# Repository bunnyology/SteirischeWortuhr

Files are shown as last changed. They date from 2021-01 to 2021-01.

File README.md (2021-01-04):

# SteirischeWortuhr
Wortuhr im steirischen Dialekt (Arduino/3D Druck)

Diese Wortuhr zeigt die aktuelle Uhrzeit auf Steirisch an. Dabei sind nicht nur die Zahlenworte in Mundart gehalten, sondern auch die eigentümliche- und für Nicht-Steirer wohl auch verwirrende Angabe der Uhrzeit ist dem lokalen Sprachgebrauch nachempfunden (14 Uhr 15 wird z.B. als "viertel Drei (!)" angegeben.

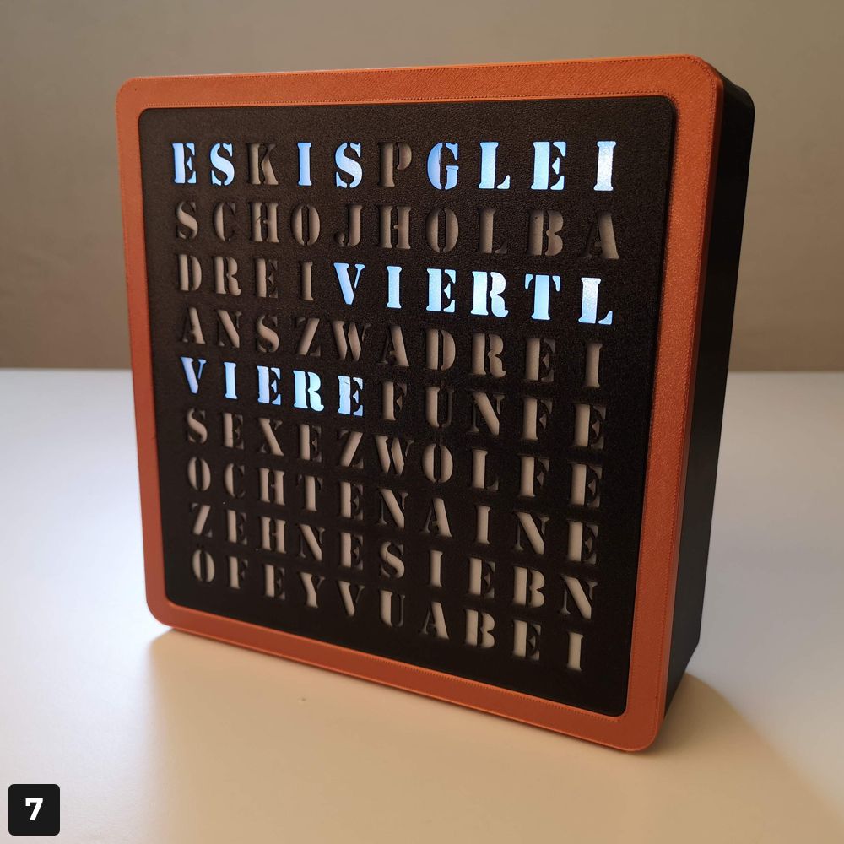
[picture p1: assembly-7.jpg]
Wortuhr


# Elektronik
Gesteuert wird die Uhr mit einem Arduino Nano und ein DCF-77 Funkuhrempfänger stellt die Zeit automatisch sekundengenau ein.

Sollte man nicht im 1500km Umkreis von Frankfurt wohnen, kann diese Antenne auch eingespart, und die Uhrzeit mit der Taste eingestellt werden.

Ich habe versucht, die Elektronik so simpel wie nur Möglich zu halten und auch auf LED Treiber verzichtet. Der Arduino treibt die eingesetzten 5mm LEDs ohne weitere Elektronik. Dafür habe ich Ultrabright LEDs eingesetzt (ca. 14000 mcd bei 20mA) und treibe diese mit 4mA um unter den Limits des Microcontrollers u bleiben. Da jedoch diese Ultrabright LEDs meistens einen sehr engen Abstrahlwinkel haben (was zu einer unregelmäßigen Ausleuchtung führen würde), habe ich die Köpfe der LEDs flach abgeschliffen.

Um die "Produktion" zu vereinfachen, habe ich eine eigene Platine fertigen lassen. Die KiCAD Schematics und PCB Daten sind hier herunterladbar, ebenso die Gerber Daten für die Platinenproduktion. Will man aber nur eine einzige Uhr herstellen, kann die Elektronik auch ganz einfach nur verkabelt werden. Der Verdratungsplan ist recht simpel:

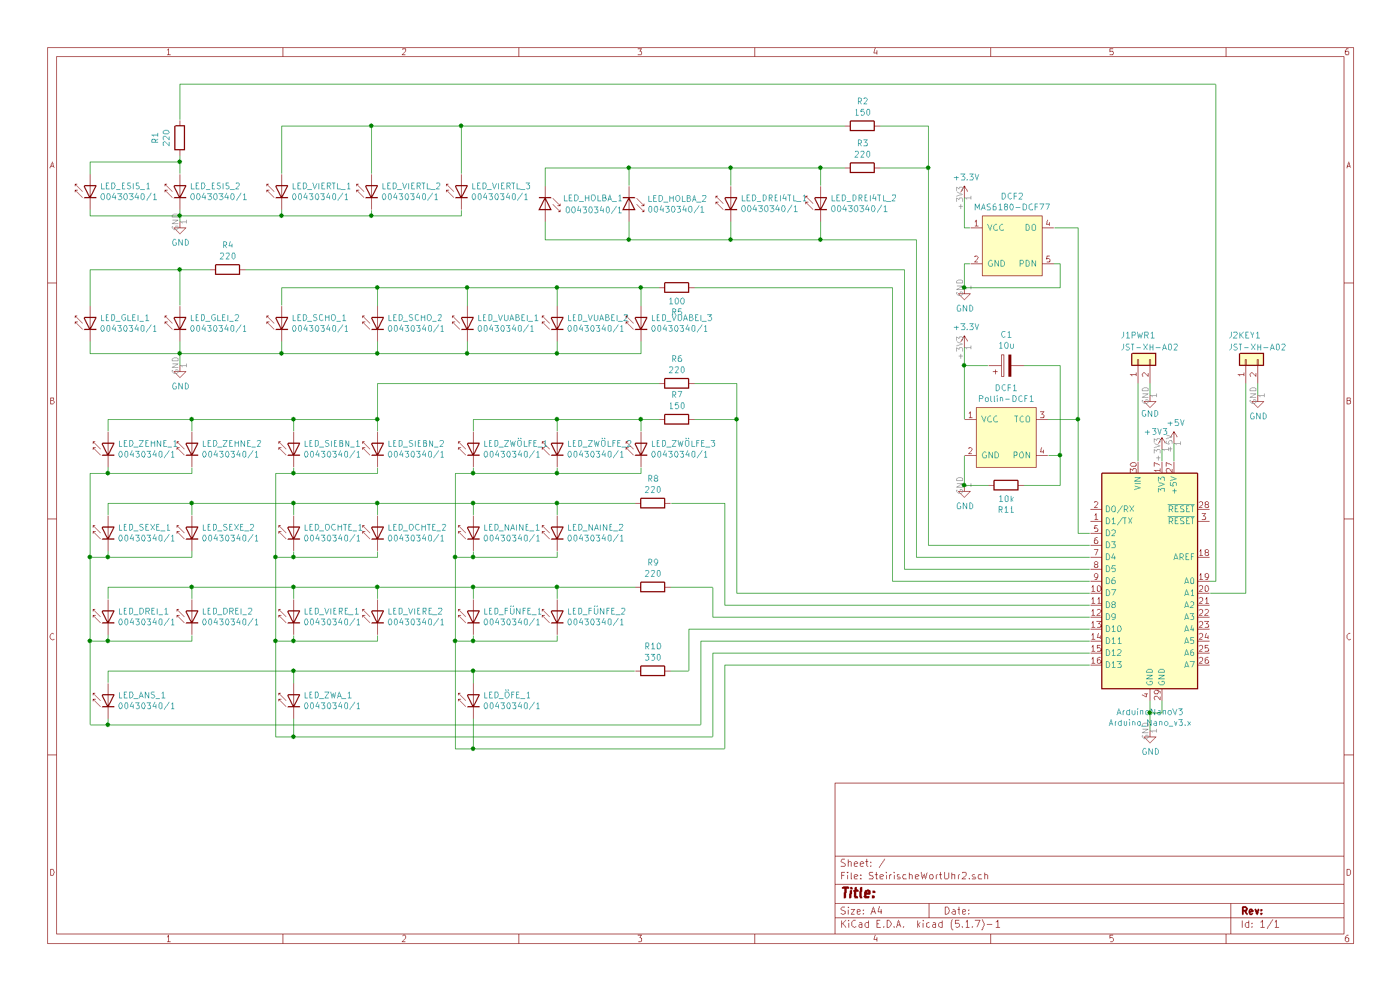
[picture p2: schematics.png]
Verdratungsplan


# Bedienung der Wortuhr
Die Uhr wird über ein 12V Netzteil mit Strom versorgt und startet beim Einstecken des Netzteilsteckers automatisch. Wird während des Einschaltens der Taster gedrückt, startet der Selbstcheck (die Uhr läuft einen 12 Stunden Zyklus schnell durch).

Solange kein Zeitpacket empfangen wird blinkt "GLEI" im Sekundentakt. Wird ein Synchronisationssignal erkannt (jede volle Minute), erhöht sich die Blinkgeschindigkeit (500ms). Sobald die Zeitinformation empfangen wird (ab Sekunde 20), verdoppelt sich die Blinkgeschwindigkeit noch einmal, bis die gesamte Uhrzeit eingelesen wurde. Dann wird die empfangene Uhrzeit angezeigt.

Hinweis: Das DCF-77 Signal ist recht schwach, und daher die Ausrichtung der Antenne wichtig. Die Uhr solle für einen guten Empfang nach Frankfurt ausgerichtet sein (Anzeige in oder gegen Blickrichtung Frankfurt).

Ist ein Empfang nicht möglich, kann die Uhrzeit auch über den Taster eingestellt werden. Dazu muss der Taster 3 Sekunden gedrückt gehalten werden. "ES IS" fängt dann zu blinken an und mit weiteren kurzen Tastendrucks kann die Uhrzeit in 5 Minuten Schritten eingestellt werden. Erneutes 3 Sekunden Drücken speichert die Uhrzeit und "ES IS" leuchtet wieder konstant.
Sobald ein Zeitpacket empfangen wird, synchronisiert sich die Uhrzeit wieder automatisch.

Die Helligkeit der Anzeige kann in vier Stufen durch kurzes Drücken des Tasters eingestellt werden.

# 3D Druck

Die 3D Modelle und Druckdateien können hier heruntergeladen werden:

https://www.prusaprinters.org/prints/44454-steirische-wort-uhr-styrian-dialect-word-clock

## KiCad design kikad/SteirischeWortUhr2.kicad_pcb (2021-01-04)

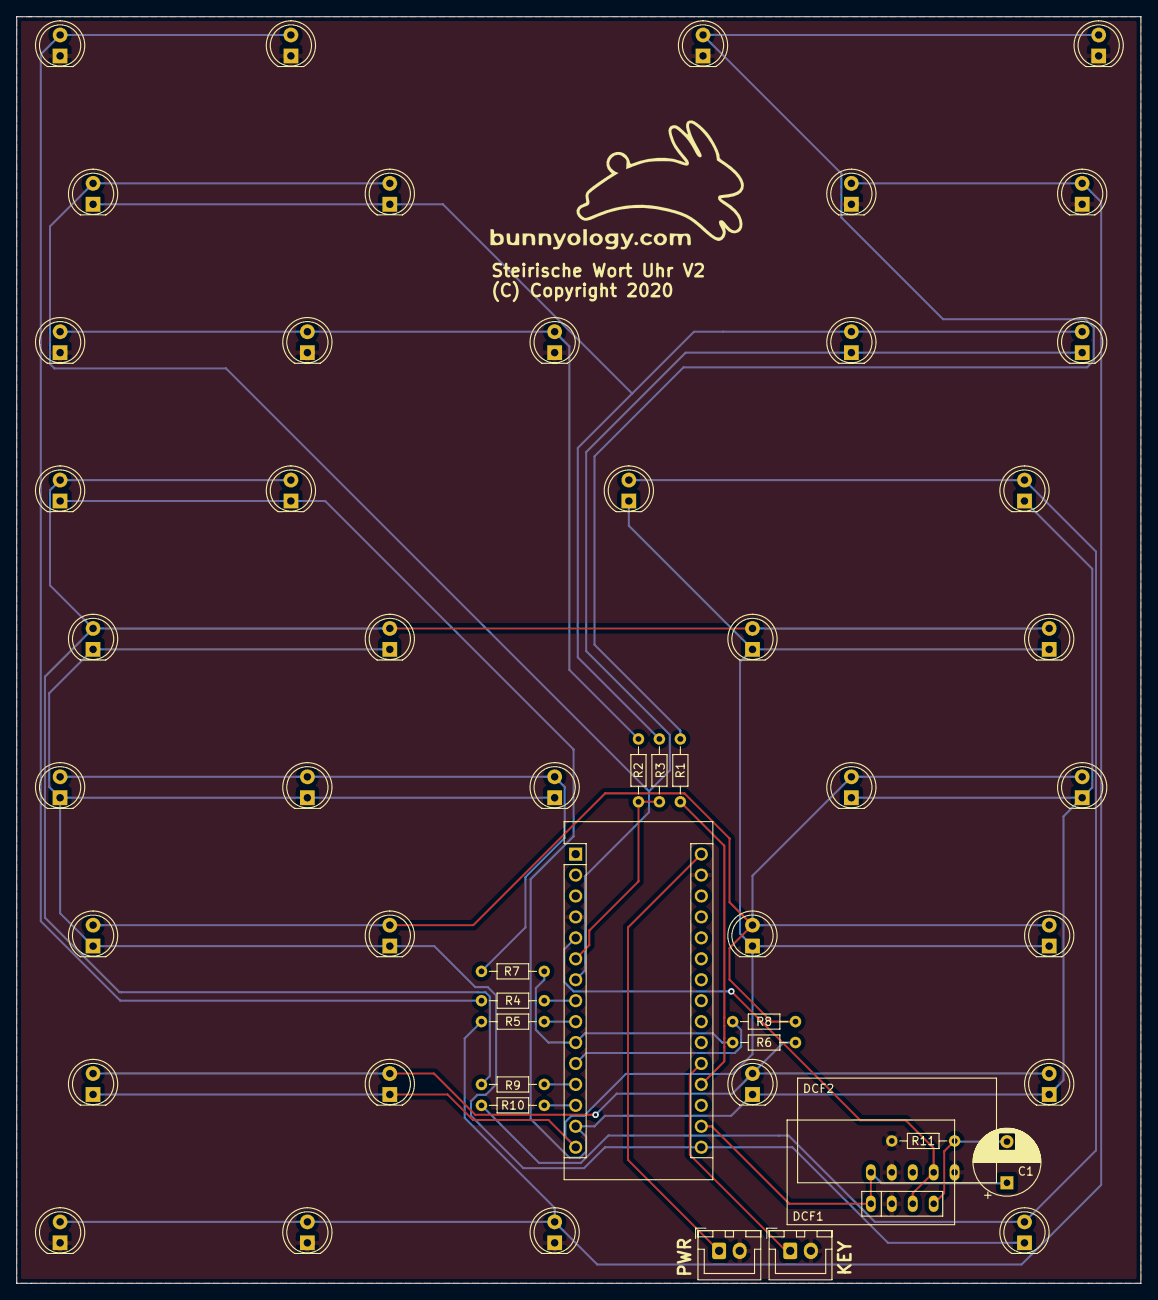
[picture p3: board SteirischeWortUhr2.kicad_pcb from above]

Board: 2 copper layers, 136.4 x 153.7 mm, 55 parts (0 on the bottom side), 28 nets.

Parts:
ArduinoNanoV3: Arduino_Nano_v3.x; Arduino_Nano
C1: 10u; CP_Radial_D8.0mm_P5.00mm
DCF1: Pollin-DCF1; Pollin-DFC77
DCF2: MAS6180-DCF77; MAS6180B1-DFC77
J1PWR1, J2KEY1: JST-XH-A02; JST_XH_B2B-XH-A_1x02_P2.50mm_Vertical
LED_ANS_1: 00430340/1; LED_D5.0mm_IRGrey
LED_DREI4TL_1, LED_DREI4TL_2: 00430340/1; LED_D5.0mm_IRGrey
LED_DREI_1, LED_DREI_2: 00430340/1; LED_D5.0mm_IRGrey
LED_ESIS_1, LED_ESIS_2: 00430340/1; LED_D5.0mm_IRGrey
LED_FÜNFE_1, LED_FÜNFE_2: 00430340/1; LED_D5.0mm_IRGrey
LED_GLEI_1, LED_GLEI_2: 00430340/1; LED_D5.0mm_IRGrey
LED_HOLBA_1, LED_HOLBA_2: 00430340/1; LED_D5.0mm_IRGrey
LED_NAINE_1, LED_NAINE_2: 00430340/1; LED_D5.0mm_IRGrey
LED_OCHTE_1, LED_OCHTE_2: 00430340/1; LED_D5.0mm_IRGrey
LED_SCHO_1, LED_SCHO_2: 00430340/1; LED_D5.0mm_IRGrey
LED_SEXE_1, LED_SEXE_2: 00430340/1; LED_D5.0mm_IRGrey
LED_SIEBN_1, LED_SIEBN_2: 00430340/1; LED_D5.0mm_IRGrey
LED_VIERE_1, LED_VIERE_2: 00430340/1; LED_D5.0mm_IRGrey
LED_VIERTL_1, LED_VIERTL_2, LED_VIERTL_3: 00430340/1; LED_D5.0mm_IRGrey
LED_VUABEI_1, LED_VUABEI_2, LED_VUABEI_3: 00430340/1; LED_D5.0mm_IRGrey
LED_ZEHNE_1, LED_ZEHNE_2: 00430340/1; LED_D5.0mm_IRGrey
LED_ZWA_1: 00430340/1; LED_D5.0mm_IRGrey
LED_ZWÖLFE_1, LED_ZWÖLFE_2, LED_ZWÖLFE_3: 00430340/1; LED_D5.0mm_IRGrey
LED_ÖFE_1: 00430340/1; LED_D5.0mm_IRGrey
R1, R3, R4, R6, R8, R9: 220; R_Axial_DIN0204_L3.6mm_D1.6mm_P7.62mm_Horizontal
R2, R7: 150; R_Axial_DIN0204_L3.6mm_D1.6mm_P7.62mm_Horizontal
R5: 100; R_Axial_DIN0204_L3.6mm_D1.6mm_P7.62mm_Horizontal
R10: 330; R_Axial_DIN0204_L3.6mm_D1.6mm_P7.62mm_Horizontal
R11: 10k; R_Axial_DIN0204_L3.6mm_D1.6mm_P7.62mm_Horizontal

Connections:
+3V3: ArduinoNanoV3.17, C1.1, DCF1.1, DCF2.1
GND: ArduinoNanoV3.4, ArduinoNanoV3.29, DCF1.2, DCF2.2, DCF2.5, J1PWR1.2, J2KEY1.2, LED_ESIS_1.1, LED_ESIS_2.1, LED_GLEI_1.1, LED_GLEI_2.1, LED_SCHO_1.1, LED_SCHO_2.1, LED_VIERTL_1.1, LED_VIERTL_2.1, LED_VIERTL_3.1, LED_VUABEI_1.1, LED_VUABEI_2.1, LED_VUABEI_3.1, R11.1
unnamed: ArduinoNanoV3.5, DCF1.3, DCF2.4
unnamed: ArduinoNanoV3.6, R2.1, R3.1
unnamed: ArduinoNanoV3.7, LED_DREI4TL_1.1, LED_DREI4TL_2.1, LED_HOLBA_1.2, LED_HOLBA_2.2
unnamed: ArduinoNanoV3.8, R4.1
unnamed: ArduinoNanoV3.9, R5.2
unnamed: ArduinoNanoV3.10, R6.1, R7.1
unnamed: ArduinoNanoV3.11, R8.1
unnamed: ArduinoNanoV3.12, R9.1
unnamed: ArduinoNanoV3.13, R10.1
unnamed: ArduinoNanoV3.14, LED_ANS_1.1, LED_DREI_1.1, LED_DREI_2.1, LED_SEXE_1.1, LED_SEXE_2.1, LED_ZEHNE_1.1, LED_ZEHNE_2.1
unnamed: ArduinoNanoV3.15, LED_OCHTE_1.1, LED_OCHTE_2.1, LED_SIEBN_1.1, LED_SIEBN_2.1, LED_VIERE_1.1, LED_VIERE_2.1, LED_ZWA_1.1
unnamed: ArduinoNanoV3.16, LED_FÜNFE_1.1, LED_FÜNFE_2.1, LED_NAINE_1.1, LED_NAINE_2.1, LED_ZWÖLFE_1.1, LED_ZWÖLFE_2.1, LED_ZWÖLFE_3.1, LED_ÖFE_1.1
unnamed: ArduinoNanoV3.19, R1.1
unnamed: ArduinoNanoV3.20, J2KEY1.1
unnamed: ArduinoNanoV3.30, J1PWR1.1
unnamed: C1.2, DCF1.4, R11.2
unnamed: LED_ANS_1.2, LED_ZWA_1.2, LED_ÖFE_1.2, R10.2
unnamed: LED_DREI4TL_1.2, LED_DREI4TL_2.2, LED_HOLBA_1.1, LED_HOLBA_2.1, R3.2
unnamed: LED_DREI_1.2, LED_DREI_2.2, LED_FÜNFE_1.2, LED_FÜNFE_2.2, LED_VIERE_1.2, LED_VIERE_2.2, R9.2
unnamed: LED_ESIS_1.2, LED_ESIS_2.2, R1.2
unnamed: LED_GLEI_1.2, LED_GLEI_2.2, R4.2
unnamed: LED_NAINE_1.2, LED_NAINE_2.2, LED_OCHTE_1.2, LED_OCHTE_2.2, LED_SEXE_1.2, LED_SEXE_2.2, R8.2
unnamed: LED_SCHO_1.2, LED_SCHO_2.2, LED_VUABEI_1.2, LED_VUABEI_2.2, LED_VUABEI_3.2, R5.1
unnamed: LED_SIEBN_1.2, LED_SIEBN_2.2, LED_ZEHNE_1.2, LED_ZEHNE_2.2, R6.2
unnamed: LED_VIERTL_1.2, LED_VIERTL_2.2, LED_VIERTL_3.2, R2.2
unnamed: LED_ZWÖLFE_1.2, LED_ZWÖLFE_2.2, LED_ZWÖLFE_3.2, R7.2

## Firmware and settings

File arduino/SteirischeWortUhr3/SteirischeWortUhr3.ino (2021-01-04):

/* ----------------------------------------------------------------------
 * Steirische Wort Uhr
 * ----------------------------------------------------------------------
 * Version: 3 / 01.11.2020
 * Target: Arduino Nano, ATmega328 
 * Copyright (C) 2020 by bunnyology
 * Author: Thomas Hasiba
 * 
 */

// a high/low cycle:
volatile unsigned long t0HI, t0LO;
volatile int tHI, tLO;

const int tolerance = 50;     // time tolerance of DCF signal in ms

volatile int rcvBIT;          // next index of bit to read in current packet (or -1 if stream is not synchronized)
volatile unsigned int tc;     // bits 20-35 of current packet

// The following variables are used to hand over a recevied time from the interrupt service
// routine to the main loop.
volatile unsigned int timecode;           // "tc" is copied into here, when 35th bit is read
volatile unsigned long timecode_millis;   // millis when "timecode" became valid (second 36 of minute)

// the actual time is stored here (once the time is set)
int tt_hour, tt_min, tt_sec, tt_ms;       // "readable" time of clock
unsigned long tt_millis;                  // time of last clock update

bool modeSync;                // when the time is set, this becomes "true"
bool modeSetup;               // "true", when the clock is in setup mode

const unsigned long LOOP_DELAY = 5;

int keyDown;                  // counts the time, the key is pressed

const int KEYDOWN_ENTER = 3000 / LOOP_DELAY;
const int KEYDOWN_RESET = 6000 / LOOP_DELAY;
const int KEYDOWN_CLICK = 1000 / LOOP_DELAY;

// this pwm pattern is controlling the light brightness by swithcing on/off the lights according to the pattern
unsigned int pwmMode = 0;
unsigned int pwmIdx = 0;
bool pwmPattern[6];

const bool PWM_PATTERN_0[] = { true, true, true, true, true, true };
const bool PWM_PATTERN_1[] = { true, true, false, true, true, false };
const bool PWM_PATTERN_2[] = { true, false, true, false, true, false };
const bool PWM_PATTERN_3[] = { true, false, false, true, false, false };


const int PIN_DCF77 = 2;      // pin 2 is connected to DCF77 output

// The array "pattern" contains the pattern for PORTD and PORTB output for cobinded
// minute and hour output.
// |                     PORTB                     |                    PORTD                      |
// +-----+-----+-----+-----+-----+-----+-----+-----|-----+-----+-----+-----+-----+-----+-----+-----+
// | 15  | 14  | 13  | 12  | 11  | 10  |  9  |  8  |  7  |  6  |  5  |  4  |  3  |  2  |  1  |  0  |
// |  ~  |  ~  |  -  |  -  |  -  |  +  |  +  |  +  |  +  | OVR | SOON| QUTR| HALF|  ~  |  ~  |  ~  |
// |     |     |5,9, |2,4, |1,3, |1,2, |3,4, |6,8, |7,10,|     |     |     |     |     |     |     |
// |     |     |11,12|7,8  |6,10 |  11 |  5, |  9, |  12 |     |     |     |     |     |     |     |
// +-----+-----+-----+-----+-----+-----+-----+-----|-----+-----+-----+-----+-----+-----+-----+-----+
// D0..7 in PORTD, D8..13 in PORTB

const unsigned int pattern[] =
  {
    (B00011000*256)+B10000000,      // 0h/12h ~ ES IS ...
    (B00110100*256)+B01000000,      // 1h/13h ~ ES IS "SCHO ... VUABEI"
    (B00101100*256)+B00111001,      // 2h/14h ~ ES IS "GLEI VIERTL ...(+1)"
    (B00110010*256)+B00011001,      // 3h/15h ~ ES IS "VIERTL ...(+1)"
    (B00101010*256)+B01011001,      // 4h/16h ~ ES IS "SCHO VIERTL ...(+1) VUABEI"
    (B00011010*256)+B00110001,      // 5h/17h ~ ES IS "GLEI HOLBA ...(+1)"
    (B00110001*256)+B00010001,      // 6h/18h ~ ES IS "HOLBA ...(+1)"
    (B00101000*256)+B11010001,      // 7h/19h ~ ES IS "SCHO HOLBA ...(+1) VUABEI"
    (B00101001*256)+B00101001,      // 8h/20h ~ ES IS "GLEI DREIVIERTL ...(+1)"
    (B00011001*256)+B00001001,      // 9h/21h ~ ES IS "DREIVIERTL ...(+1)"
    (B00110000*256)+B11001001,      // 10h/22h ~ ES IS "SCHO DREIVIERTL ...(+1) VUABEI"
    (B00011100*256)+B00100001       // 11h/23h ~ ES IS "GLEI ...(+1)"
  };

const unsigned int MASK_MINUTE =  (B00000000*256)+B01111000;
const unsigned int MASK_HOUR =    (B00111111*256)+B10000000;
const unsigned int MASK_INCDAY =  (B00000000*256)+B00000001;

// some special display commands...
const unsigned int CMD_OFF =      (B00111000*256)+B00000000;
const unsigned int CMD_WAIT =     (B00111000*256)+B00100000;    // "WAIT" display (blinks, when not sync'd)


void setup() {

  // setup all LED outputs
  pinMode( 3, OUTPUT );
  pinMode( 4, OUTPUT );
  pinMode( 5, OUTPUT );
  pinMode( 6, OUTPUT );
  pinMode( 7, OUTPUT );
  pinMode( 8, OUTPUT );
  pinMode( 9, OUTPUT );
  pinMode( 10, OUTPUT );
  pinMode( 11, OUTPUT );
  pinMode( 12, OUTPUT );
  pinMode( 13, OUTPUT );

  pinMode( A0, OUTPUT );
 
  // reset ALL OFF
  digitalWrite( A0, HIGH );
  setLightbox( CMD_OFF );

  // set input pin
  pinMode( A1, INPUT_PULLUP );

  // make visual check of Lightbox
  if( digitalRead( A1 ) == LOW ) {
    // key pressed during start-up -> run self check
    selfcheck();
  }

  // setup the DCF77 input
  t0HI = t0LO = 0;
  tHI = tLO = 0;
  rcvBIT = -1;
  timecode = 0;
  
  pinMode( PIN_DCF77, INPUT );    // the Pollin DCF77 does not work with INPUT_PULLUP
  attachInterrupt( digitalPinToInterrupt( PIN_DCF77 ), dcf77_isr, CHANGE );

  setPWMMode( 0 );
  modeSync = false;
  modeSetup = false;
}

void loop() {

  if( keyDown < 0 ) keyDown = 0;
  if( digitalRead( A1 ) == LOW ) {
    keyDown++;
  } else if( keyDown > 0 ) {
    keyDown = -keyDown;
  }

  if( modeSetup ) {

    if( keyDown == KEYDOWN_ENTER ) {
      // end set-up mode
      modeSetup = false;
      keyDown = KEYDOWN_CLICK; // set to KEYDOWN_CLICK to avoid triggering another click event
      modeSync = true;
      digitalWrite( A0, HIGH );
      tt_millis = millis();
      delay( LOOP_DELAY );
      return;
      
    } else if( keyDown > KEYDOWN_RESET ) {
      // long press -> reset
      keyDown = 0;
      modeSetup = false;
      modeSync = false;
      delay( LOOP_DELAY );
      return;
    }

    if(( keyDown < 0 ) && ( keyDown > -KEYDOWN_CLICK )) {
      incFiveMinutes();
    }

    // let "ES IS" blink
    if(( millis() % 500 ) < 250 ) digitalWrite( A0, HIGH ); else digitalWrite( A0, LOW );
    updateLightbox();

    delay( LOOP_DELAY );
    return;

  } else {
    // not in set-up mode yet
    if( keyDown > KEYDOWN_ENTER ) {
      // engage set-up mode
      tt_sec = 0;
      tt_min = ( tt_min / 5 ) * 5;
      modeSetup = true;
      delay( LOOP_DELAY );
      return;
    } else if(( keyDown < 0 ) && ( keyDown > -KEYDOWN_CLICK )) {
      // key clicked -> change brightness
      setPWMMode( ++pwmMode );
    }
  }

  
  
  if( timecode != 0 ) {
    // synchronization event

    // check validity of time packet
    if(( bitRead(timecode,0) == 0 )
      || (( bitRead(timecode,1)
           +bitRead(timecode,2)
           +bitRead(timecode,3)
           +bitRead(timecode,4)
           +bitRead(timecode,5)
           +bitRead(timecode,6)
           +bitRead(timecode,7)
           +bitRead(timecode,8)) % 2 == 1 )
      || (( bitRead(timecode,9)
           +bitRead(timecode,10)
           +bitRead(timecode,11)
           +bitRead(timecode,12)
           +bitRead(timecode,13)
           +bitRead(timecode,14)
           +bitRead(timecode,15)) % 2 == 1 )) {
      // time packet is invalid -> ignore
      timecode = 0;
      return;        
    }

    // set time
    int _min = bitRead(timecode,1)
        + 2*bitRead(timecode,2)
        + 4*bitRead(timecode,3)
        + 8*bitRead(timecode,4)
        + 10*bitRead(timecode,5)
        + 20*bitRead(timecode,6)
        + 40*bitRead(timecode,7);
    int _hour = bitRead(timecode,9)
        + 2*bitRead(timecode,10)
        + 4*bitRead(timecode,11)
        + 8*bitRead(timecode,12)
        + 10*bitRead(timecode,13)
        + 20*bitRead(timecode,14);

    // sanity check the time
    if(( _min > 59 ) || ( _hour > 23 )) {
      // time os nonsense -> ignore and reset package
      timecode = 0;
      return;
    }

    // the time seems to be valid -> set time of clock, now
    tt_hour = _hour;
    tt_min = _min;
    tt_sec = 36;      // we have still not read the full packet, we are in second 36 of previous minute
    tt_ms = 0;
    tt_millis = timecode_millis;

    // the minute decoded has not yet started; hence, set time to the minute before...
    decMinute();

    timecode = 0;
    modeSync = true;
    
    // show time of clock now
    updateLightboxPWM();

  } else if( modeSync ) {
    // time is sync'd
    
    // update time
    unsigned long ts = millis();
    // check for overflow
    int delta_ms = 0;
    if( ts < tt_millis ) {
      // handle timer overflow...
      delta_ms = 4294967295ul - tt_millis + ts + 1;
    } else {
      delta_ms = ts - tt_millis;      
    }

    if( tt_ms + delta_ms < 1000 ) {
      // does not increase seconds...
      tt_ms += delta_ms;
      tt_millis = ts;
      
    } else {
      delta_ms -= 1000 - tt_ms;
      tt_ms = 0;
      incSecond();
      while( delta_ms >= 1000 ) {
        delta_ms -= 1000;
        incSecond();
      }
      tt_ms += delta_ms;
      tt_millis = ts;
    }
    
    // time has probably changed -> update display
    updateLightboxPWM();

  } else {
    // not sync'd yet
    digitalWrite( A0, LOW );
    
    if( rcvBIT < 0 ) {
      if(( millis() % 2000 ) < 1000 ) setLightbox( CMD_OFF ); else setLightbox( CMD_WAIT );
    } else if( rcvBIT >= 20 ) {
      if(( millis() % 500 ) < 250 ) setLightbox( CMD_OFF ); else setLightbox( CMD_WAIT );
    } else {
      if(( millis() % 1000 ) < 500 ) setLightbox( CMD_OFF ); else setLightbox( CMD_WAIT );
    }
  }
  
  delay( LOOP_DELAY );
}


/** 
 * DCF77 Interrupt Handler
 */
void dcf77_isr() {
  long ts = millis();
  int state = digitalRead( PIN_DCF77 );
  if( state == LOW ) {
    // HIGH->LOW change - capture AMP-modulation spike
    tHI = ts - t0HI;
    t0LO = ts;
    return;
  }
  // LOW->HIGH change - capture carrier
  tLO = ts - t0LO;
  t0HI = ts;

  if( rcvBIT < 0 ) {
    // not sync'd - check for sync'ing pause (1800 or 1900ms)
    if(( tLO > 1800-tolerance ) && ( tLO < 1900+tolerance )) {
      // stream synchronization
      rcvBIT = 0;
      tc = 0;
    }
    return;
  }

  // try to match timings and identify bit value
  if(( tLO > 800-tolerance ) && ( tLO < 800+tolerance )) {
    // received "1"
    if(( rcvBIT >= 20 ) && ( rcvBIT < 36 )) {
      // time information
      bitSet( tc, rcvBIT-20 );
    }
    rcvBIT++;
    
  } else if(( tLO > 900-tolerance ) && ( tLO < 900+tolerance )) {
    // received "0"
    rcvBIT++;
    
  } else {
    // error - reset stream sync
    rcvBIT = -1;
    return;
  }
  if( rcvBIT == 36 ) {
    // time information is ready -> notify
    timecode_millis = ts;
    timecode = tc;
    
  } else if( rcvBIT == 59 ) {
    // packet finished 
    rcvBIT = -1;
  }
}

/**
 * incSecond
 * Increases the time of clock by one second, handling all overruns
 */
void incSecond() {
  tt_sec++;
  
  // check for second overflow
  if( tt_sec == 60 ) {
    tt_sec = 0;
    tt_min++;

    // check for minute overflow
    if( tt_min == 60 ) {
      tt_hour++;
      tt_min = 0;

      // check for hour overflow
      if( tt_hour == 24 ) tt_hour = 0;
    }
  }
}

/**
 * decMinute
 * Decreases the time of clock by one minute, handling all overruns.
 */
void decMinute() {
  if( tt_min > 0 ) {
    // no underrun
    tt_min--;
    return;
  }
  // handle minute underrun
  tt_min = 59;
  if( tt_hour > 0 ) {
    // no hour underron
    tt_hour--;
    return;
  }
  tt_hour = 23;
  return;
}

void incMinute() {
  tt_min++;

  // check for minute overflow
  if( tt_min == 60 ) {
    tt_hour++;
    tt_min = 0;

    // check for hour overflow
    if( tt_hour == 24 ) tt_hour = 0;
  }
}

void incFiveMinutes() {
  incMinute();
  incMinute();
  incMinute();
  incMinute();
  incMinute();
}

void setLightbox( unsigned int cmd ) {
  PORTB = highByte(cmd);
  PORTD = lowByte(cmd);
}

void updateLightbox() {
  int hour = tt_hour;
  int minute = tt_min;

  // once again, check time to avoid showing some ridiculous time
  if(( minute < 0 ) || ( minute > 59 ) || ( hour < 0 ) || ( hour > 23 )) {
    // invalid time
    setLightbox( CMD_OFF );
    return;
  }

  unsigned int cmd = pattern[ minute / 5 ];
  if(( cmd & MASK_INCDAY ) == 1 ) {
    hour++;
    if( hour == 24 ) hour = 0;
  }
  if( hour > 11 ) hour -= 12;
  cmd &= MASK_MINUTE;
  cmd |= pattern[hour] & MASK_HOUR;

  setLightbox( cmd );
}

void updateLightboxPWM() {
    pwmIdx++;
    if ( pwmIdx >=sizeof(pwmPattern) ) pwmIdx = 0;
    if( pwmPattern[pwmIdx] ) {
      digitalWrite( A0, HIGH );
      updateLightbox();
    } else {
      digitalWrite( A0, LOW );
      setLightbox( CMD_OFF );
    }
}

void setPWMMode( unsigned int mode ) {
  if( mode > 3 ) mode = 0;
  pwmMode = mode;
  switch( pwmMode ) {
    case 0 : for( int i = 0; i < sizeof(pwmPattern); i++ ) pwmPattern[i] = PWM_PATTERN_0[i]; break;
    case 1 : for( int i = 0; i < sizeof(pwmPattern); i++ ) pwmPattern[i] = PWM_PATTERN_1[i]; break;
    case 2 : for( int i = 0; i < sizeof(pwmPattern); i++ ) pwmPattern[i] = PWM_PATTERN_2[i]; break;
    case 3 : for( int i = 0; i < sizeof(pwmPattern); i++ ) pwmPattern[i] = PWM_PATTERN_3[i]; break;
  }
  pwmIdx = 0;
}

/**
 * selfcheck
 * Shows all possible times of a (half) day (144 combination) for
 * 250ms each. Total time for selfcheck = 12*12*250ms = 36 sec.
 */
void selfcheck() {

  int blnk = 0;
  digitalWrite( A0, HIGH );

  for( tt_hour = 0; tt_hour < 12; tt_hour++ ) {
    for( tt_min = 0; tt_min < 60; tt_min += 5 ) {
      updateLightbox();

      blnk++;
      if( blnk == 4 ) digitalWrite( A0, LOW );
      else if( blnk == 8 ) {
        digitalWrite( A0, HIGH );
        blnk = 0;
      }
      
      delay(100);
    }
  }

  tt_hour = 0;
  tt_min = 0;
  
  digitalWrite( A0, LOW );

}

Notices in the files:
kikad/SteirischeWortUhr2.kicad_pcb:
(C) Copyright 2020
